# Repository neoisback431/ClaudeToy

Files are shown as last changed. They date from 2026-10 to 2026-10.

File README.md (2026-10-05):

# ClaudeToy

Un petit compagnon physique pour Claude Desktop : un écran rond avec **Clawd**, la mascotte pixel-art de
Claude Code, qui réagit à ce que fait Claude (au travail, en attente de validation, terminé…) et te laisse
**approuver ou refuser** les demandes de permission depuis un bouton tactile.

*A tiny physical Claude Desktop companion on an ESP32-S3 + round GC9A01 display, with touch buttons to approve or deny
permission prompts. Port of the official [claude-desktop-buddy](https://github.com/anthropics/claude-desktop-buddy)
(M5StickC Plus) to other hardware, with a 3D-printable case.*

<table>
  <tr>
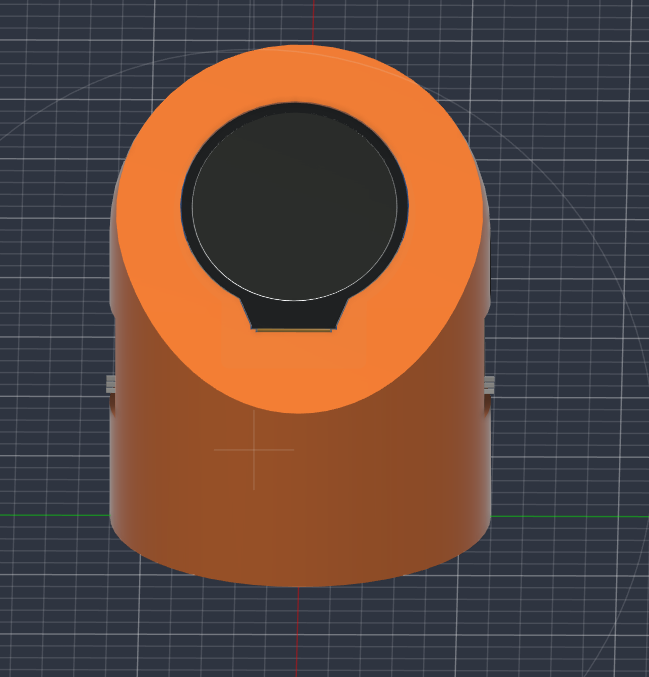
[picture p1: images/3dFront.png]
Vue de face du boîtier
    <td align="center"><br><sub>Face avant : l'écran rond sur la face inclinée</sub></td>
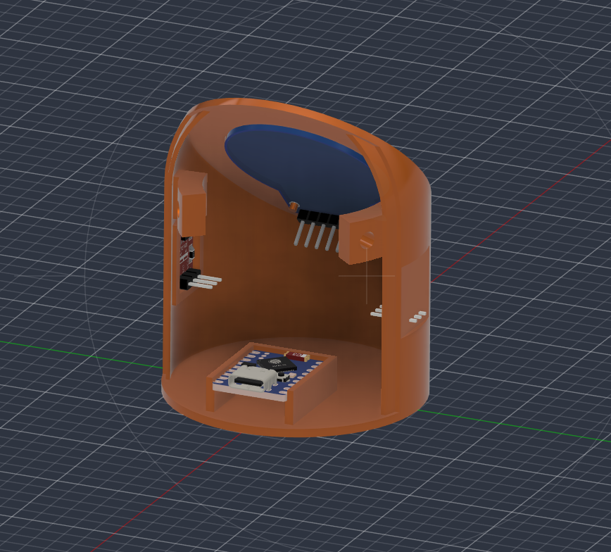
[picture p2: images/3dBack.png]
Vue en coupe du boîtier
    <td align="center"><br><sub>Vue arrière (trappe retirée) : ESP32-S3 et modules dans le corps</sub></td>
  </tr>
</table>

> **Base logicielle :** la partie logicielle de ce projet (firmware, protocole Bluetooth, animaux, menus, statistiques) repose en grande
> partie sur le projet [anthropics/claude-desktop-buddy](https://github.com/anthropics/claude-desktop-buddy) (licence MIT, © Anthropic, PBC),
> adapté ici à d'autres composants. Voir [Licence et crédits](#licence-et-crédits).
>
> Projet communautaire non officiel, sans lien avec Anthropic. La fonction « Hardware Buddy » de Claude Desktop est
> réservée au mode développeur et n'est pas une fonctionnalité officiellement supportée.

## Ce que ça fait

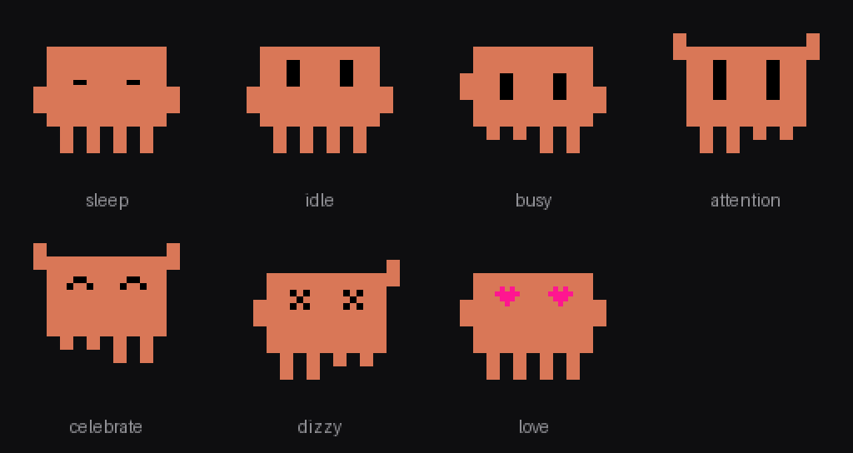
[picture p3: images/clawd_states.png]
Les 7 états de Clawd
<p align="center"><br><sub>Les sept états de Clawd (rendu illustratif de l'animation du firmware)</sub></p>

- **Clawd réagit à Claude** : il dort, attend, travaille, s'inquiète quand une permission est demandée, fête une réussite…
- **Approbation physique** : tap pour approuver, un autre geste (ou un 2e bouton) pour refuser.
- **Écran de veille** : heure et date, tokens du jour, niveau et progression, sessions en cours/en attente,
  état du Bluetooth, dernier message de Claude.
- **Bluetooth LE chiffré** avec appairage par code à 6 chiffres affiché à l'écran.

## Informations affichées

Tout vient de Claude Desktop, par Bluetooth LE : l'état des sessions, les tokens, les dernières lignes du transcript,
la demande de permission en cours (outil + commande), l'heure et ton prénom. Rien ne transite par Internet.

| Écran | Quand | Contenu |
| ----- | ----- | --- |
| **Veille** | aucune session en cours ni en attente | Heure (deux-points clignotants) et date ; **tokens du jour** ; **niveau** (Lv) avec barre de progression vers le suivant (50 000 tokens par niveau) ; sessions **en cours** et **en attente** ; état du **Bluetooth** (vert = chiffré, orange = non chiffré, gris = déconnecté) ; **dernier message** de Claude sur 2 lignes ; avec la status line : **modèle, effort et % de contexte** (ex. `Opus 4.5 high 42%`) |
| **Bague de contexte** | dès que la status line de Claude Code est branchée (voir plus bas) | 60 points autour du bord de l'écran, remplis dans le sens horaire selon le **contexte utilisé** : vert, puis jaune (60 %), orange (80 %) et rouge (90 %). Disparaît si plus rien n'arrive pendant 30 minutes |
| **Activité** | au moins une session en cours | Clawd en grand et les 3 dernières lignes du transcript (défilement avec le bouton B) |
| **Demande de permission** | Claude attend une validation | Délai d'attente (rouge après 10 s), **nom de l'outil** (ex. `Bash`), **commande ou fichier concerné** sur 2 lignes, rappel des gestes pour approuver ou refuser |
| **Pet** (tap pour y accéder) | à la demande | Page 1 : humeur (4 cœurs), faim (10 pastilles), énergie, niveau, nombre d'approbations et de refus, tokens totaux et du jour. Page 2 : explications |
| **Info** (tap) | à la demande | 6 pages : à propos, boutons, **Claude** (sessions, état du lien, ancienneté du dernier message), **appareil** (durée de fonctionnement, mémoire libre, luminosité), **Bluetooth** (nom `Claude-XXXX`, adresse, marche à suivre), crédits |
| **Menu** (appui long ou double tap) | à la demande | Réglages (luminosité, son, LED, ordre des écrans, changement d'animal, réinitialisation), éteindre, aide, mode démo |
| **Appairage** | première connexion | Code à 6 chiffres à saisir sur l'ordinateur |
| **Démarrage** | allumage | « Hello! » ou « *Prénom*'s Clawd » |

### Les états de Clawd

| État | Déclencheur |
| ---- | --- |
| sleep | nuit (1 h – 7 h), week-end, ou les 12 s après le réveil de l'écran |
| idle | connecté, rien d'urgent |
| busy | au moins une session en cours (le projet d'origine attendait 3 sessions) |
| attention | une permission attend ta réponse |
| celebrate | tâche terminée, ou niveau gagné |
| heart | permission approuvée en moins de 5 s |
| dizzy | secousse (nécessite un IMU, absent de ce montage) |

Sans IMU et sans batterie, certaines valeurs restent figées : la sieste et l'énergie ne varient pas, et l'écran
« appareil » affiche 0 % de batterie.

## Status line Claude Code (modèle, effort, contexte)

Claude Desktop n'envoie par Bluetooth ni le modèle, ni le niveau d'effort, ni le contexte. Un **mod Claude Code**,
[`mod/claudetoy-statusline`](mod/claudetoy-statusline), les lit et les envoie à la carte par le **port USB** : modèle, effort,
% de contexte et quotas 5 h / 7 j (uniquement ces champs : ni dossier de travail, ni dépôt Git). Il fonctionne dans
Claude Desktop (onglet Code) comme dans la CLI, et n'affiche rien dans Claude.

```bash
pip install pyserial
claude plugin marketplace add neoisback431/ClaudeToy
claude plugin install claudetoy-statusline@claudetoy
```

Puis `claude plugin list` doit indiquer le plugin comme chargé ; relance Claude Desktop. Si tu avais un bloc `statusLine`
pointant vers le script, retire-le de `~/.claude/settings.json` pour éviter un double envoi. Options du plugin (`/config`) :
`python` (exécutable, `python` par défaut) et `refreshSeconds` (5 par défaut).

- **Testé avec Claude Desktop** : modèle, contexte, quotas et effort remontent sur la bague. Le mod a besoin d'une version de
  Claude Code qui gère les mods ; sinon `claude plugin list` affiche une erreur de chargement.
- **Sans le mod** (CLI seule) : le script [`claudetoy_statusline.py`](mod/claudetoy-statusline/claudetoy_statusline.py) peut aussi
  servir de status line, dans `~/.claude/settings.json` :
  `"statusLine": {"type": "command", "command": "python C:/chemin/vers/mod/claudetoy-statusline/claudetoy_statusline.py", "refreshInterval": 5}`
  (barres obliques `/` sous Windows).
- L'effort est lu à chaque requête au modèle : il reste vide jusqu'à la première réponse d'une session.
- La carte doit être branchée en USB au PC qui exécute Claude Code. Si le port est occupé (flash, moniteur série) ou la carte absente,
  l'envoi est simplement ignoré.
- Les quotas 5 h / 7 j ne sont fournis que pour les abonnements Pro et Max, et le contexte reste inconnu pendant la première minute
  d'une session.
- Avec plusieurs sessions, la dernière valeur reçue s'affiche.
- L'effort est abrégé (`medium` devient `med`) et le nom du modèle est raccourci pour tenir à l'écran.
- Le script garde ses 100 derniers passages dans `%TEMP%\claudetoy_statusline.log` (heure, session, valeurs envoyées) pour diagnostiquer.
- Format du message (une ligne JSON) : `{"cc":{"m":"Opus 4.5","e":"high","c":42,"h":23,"d":41}}` (`-1` = inconnu).

## Nomenclature (BOM)

| Qté | Composant | Remarque |
| --- | --- | --- |
| 1 | ESP32-S3 Super Mini | USB natif et BLE 5. Ne convient pas : ESP32-C3 (pas de tactile natif, moins à l'aise) ni ESP8266 (pas de BLE) |
| 1 | Écran rond GC9A01 1,28" SPI, 240×240 | Versions à 7 ou 8 broches ; la broche BLK (rétroéclairage) est facultative |
| 1 à 2 | Module tactile capacitif TTP223 | 1 en mode 1 bouton, 2 en mode 2 boutons |
| 1 | Câble USB-C (données) | Alimentation et flash |
| — | Fils souples ou Dupont, barrettes à souder | 7 à 8 fils pour l'écran, 3 par module tactile |
| — | Fixations (vis, colle) | Selon ton montage |
| 1 | Corps principal imprimé en 3D | [`3dParts/Corps principal.stl`](3dParts/Corps%20principal.stl) |
| 1 | Trappe imprimée en 3D | [`3dParts/Trappe.stl`](3dParts/Trappe.stl) |

Optionnel, **non géré par le firmware** : accu Li-ion rechargeable et chargeur, schéma dans [BATTERY.md](BATTERY.md).

## Câblage

<p align="center">Schéma de câblage</p>

| Écran GC9A01 | ESP32-S3 | | Module tactile | ESP32-S3 |
| --- | --- | - | --- | --- |
| VCC | 3V3 | | A : OUT | GPIO 4 |
| GND | GND | | B : OUT (optionnel) | GPIO 2 |
| SCL | GPIO 5 | | VCC (A et B) | 3V3 |
| SDA | GPIO 6 | | GND (A et B) | GND |
| CS | GPIO 7 | | | |
| DC | GPIO 8 | | | |
| RST | GPIO 9 | | | |
| BLK (si présent) | GPIO 10 | | | |

Détails et conseils : [WIRING.md](WIRING.md).

## Boîtier 3D

| Fichier | Contenu |
| --- | --- |
| [`3dParts/Corps principal.stl`](3dParts/Corps%20principal.stl) | Corps cylindrique, environ 60 × 60 × 74 mm, face supérieure inclinée pour l'écran |
| [`3dParts/Trappe.stl`](3dParts/Trappe.stl) | Trappe d'accès, environ 22 × 58 × 71 mm |
| [`3dParts/claude_toy.f3z`](3dParts/claude_toy.f3z) | Projet complet Fusion (archive) |
| [`3dParts/claud_toy.f3d`](3dParts/claud_toy.f3d) | Modèle Fusion |

Les dimensions ci-dessus sont lues dans les fichiers STL. Les fichiers Fusion permettent d'adapter le boîtier
(emplacement des modules, taille de la carte).

## Compiler et flasher

```bash
pip install platformio esptool
python -m platformio run -t upload
```

L'upload passe par l'esptool récent (PlatformIO embarque une version qui rate le reset automatique sur l'USB natif
de l'S3). Si la carte n'est pas détectée : maintenir **BOOT**, rebrancher l'USB, relâcher après 2 s.

## Appairage avec Claude Desktop

**Documentation officielle :** [section « Pairing » du dépôt claude-desktop-buddy](https://github.com/anthropics/claude-desktop-buddy#pairing)
et [protocole détaillé (REFERENCE.md)](https://github.com/anthropics/claude-desktop-buddy/blob/main/REFERENCE.md#enabling-the-bridge).

En résumé :

1. Dans Claude Desktop (macOS ou Windows) : `Help → Troubleshooting → Enable Developer Mode`.
2. `Developer → Open Hardware Buddy…` puis **Connect** et choisir `Claude-XXXX`.
3. Saisir le code à 6 chiffres affiché sur l'écran.

Ensuite, la reconnexion est automatique. Le pont Bluetooth n'est disponible qu'en mode développeur : ce n'est pas une
fonctionnalité officiellement supportée.

## Boutons

Mode 2 boutons (par défaut, `-DBUDDY_BTNB_PIN=2`) :

| Bouton | Action |
| --- | --- |
| A, tap | approuver / écran suivant |
| A, appui long | menu |
| B | refuser / valider / page suivante |

Mode 1 bouton (commenter `BUDDY_BTNB_PIN`) : tap = A, appui long = B, double tap = menu.

## Ce qui change par rapport à l'original

- Couche de compatibilité `src/M5StickCPlus.h` + `src/m5shim.cpp` : l'API M5Stack est émulée (écran TFT_eSPI, rétroéclairage PWM,
  boutons tactiles, horloge logicielle), le reste du firmware est quasi inchangé.
- Nouvelle espèce `clawd` ([src/buddies/clawd.cpp](src/buddies/clawd.cpp)), dessinée en pixels, avec les 7 états animés.
- Tableau de bord de veille (heure, tokens du jour, niveau, sessions, Bluetooth, dernier message).
- Interface réduite à 135×208 px, centrée dans le cercle.
- Bague de contexte et ligne modèle/effort alimentées par la status line de Claude Code, via USB.

## État

- Testé sur le matériel : compilation, flash, affichage, mode 1 bouton, appairage Bluetooth avec Claude Desktop.
- Mode 2 boutons : implémenté, pas encore validé sur le matériel.
- Pas d'IMU : pas de secousse, de sieste face cachée ni d'horloge paysage. Pas de gestion de batterie dans le firmware.
- Les personnages GIF ne sont pas fournis (les GIF « bufo » du dépôt d'origine sont des œuvres de tiers) ; voir
  `tools/prep_character.py` et `tools/flash_character.py`.

## Licence et crédits

**Ce projet est un dérivé de [anthropics/claude-desktop-buddy](https://github.com/anthropics/claude-desktop-buddy)**
(licence MIT, © 2026 Anthropic, PBC). La partie logicielle s'appuie en grande partie sur ce dépôt, repris et adapté :

| Repris du projet d'origine (avec adaptations légères) | Ajouté ou réécrit ici |
| --- | --- |
| Protocole Bluetooth LE et appairage chiffré (`ble_bridge`) | Couche de compatibilité M5StickC Plus → ESP32-S3 (`M5StickCPlus.h`, `m5shim.cpp`) |
| Réception des données de Claude Desktop, statistiques, niveaux (`data.h`, `stats.h`, `xfer.h`) | Espèce `clawd` en pixel-art et ses animations |
| Moteur d'animation, 18 animaux ASCII, personnages GIF (`buddy`, `character`, `buddies/`) | Tableau de bord de veille |
| Menus, réglages, écrans Pet et Info, scripts `tools/` | Gestes sur boutons tactiles, mode 1 ou 2 boutons |
| | Câblage, documentation, boîtier 3D |

La licence MIT d'origine est conservée telle quelle dans [LICENSE](LICENSE), comme elle l'exige. Merci aux auteurs du
projet d'origine, dont le dépôt contient aussi la documentation complète du protocole.

Clawd est la mascotte de Claude Code ; le dessin pixel-art de ce dépôt est une réinterprétation non officielle.

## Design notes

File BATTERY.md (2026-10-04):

# Alimentation sur batterie — Li-ion 16340 + chargeur TP4057

## ⚠️ À vérifier avant de brancher quoi que ce soit

- **L'accu doit être un Li-ion RECHARGEABLE 3,7 V (4,2 V pleine charge).** Les piles marquées « LS… » chez
  Saft (ex. LS 17330) sont des lithium-thionyle **non rechargeables** (3,6 V) : les mettre sur un chargeur
  est dangereux (échauffement, fuite, incendie). Cherche « Li-ion », « rechargeable » ou « 4,2 V » sur l'étiquette.
- **Protection obligatoire** : le TP4057 charge, mais ne coupe pas la décharge ni les courts-circuits. Prends un
  accu **protégé** (petit circuit intégré en bout) ou ajoute un module de protection 1S (DW01A + FS8205A).
- **Courant de charge ≤ 0,5 C** : pour ~700 mAh, vise 300 à 350 mA. La plupart des modules TP405x se règlent
  avec la résistance PROG (I ≈ 1200 V / R : 3,3 kΩ ≈ 360 mA). Vérifie la valeur sur ton module (1,2 kΩ = 1 A, trop fort).

## Principe (chemin d'alimentation)

- **Sur USB** (câble branché sur le module chargeur) : l'ESP32 est alimenté par l'USB via D1 ; le MOSFET Q1
  isole l'accu du système, qui se recharge **seul** (la charge se termine correctement).
- **Sur batterie** (USB débranché) : Q1 conduit, l'accu alimente la broche 5V de la carte (chute quasi nulle,
  contrairement à une diode).
- La carte régule ensuite en 3,3 V avec son propre régulateur : l'accu 4,2 → 3,5 V donne un 3V3 stable ; en dessous
  la tension descend doucement. Le firmware coupera vers 3,3 V pour protéger l'accu.

## Schéma

```
                     ┌──────────────────────────┐
   USB-C ───────────►│ IN+        TP4057        │
                     │ (module     chargeur     │
                     │  complet)  BAT+  BAT-    │
                     └──┬───────────┬─────┬─────┘
                        │           │     │
              VUSB ─────┤           │     └──────────────────────────────── GND commun
                        │      ┌────┴─────┐
                        │      │ PROTECTION│  (inutile si accu protégé)
                        │      │ DW01+8205 │
                        │      └────┬─────┘
                        │           │ P+  / P− (vers GND commun)
                        │      ┌────┴─────┐
                        │      │  ACCU    │  Li-ion 16340, 3,7 V
                        │      │  (+) (−) │
                        │      └──────────┘
                        │           │
                        │         [SW] interrupteur à glissière sur le +
                        │           │
                        │         BATSW ──────────┬──── R3 100k ──┬── R4 100k ── GND
                        │           │             │               └─► GPIO 1  (ADC : tension accu ÷2)
                        │           │             │                   + C1 100 nF vers GND
                        │       D = Drain         │
                        │      ┌────┴────┐        │
                        │      │   Q1    │ P-MOSFET AO3401A (ou SI2301, IRLML6401)
                        ├──────┤ G       │
                        │      └────┬────┘
                        │       S = Source
                        │           │
                        │    ┌──────┴──────────────── SYS ───┬──► carte S3 : broche 5V
                        │    │                               │
                        └─►|─┘  D1 Schottky SS14 / 1N5819    ├─ C2 100 µF (près de la carte) vers GND
                      (anode = VUSB, cathode = SYS)          │
                                                             └─► (écran GC9A01 : VCC reste sur 3V3 de la carte)

   Grille de Q1 : reliée à VUSB, plus R1 100 kΩ de la grille vers GND (tire la grille à 0 V sans USB → Q1 passant).

   Détection USB :  VUSB ── R5 100k ──┬── R6 100k ── GND
                                       └─► GPIO 3   + C3 100 nF vers GND
```

Résumé des connexions :

| De | Vers |
|----|---|
| Chargeur IN+ (5 V USB) | D1 anode, grille de Q1, R1, R5 |
| D1 cathode | SYS |
| Chargeur BAT+ | accu + (via la protection) |
| Accu + | interrupteur SW → BATSW |
| BATSW | Q1 drain, R3 |
| Q1 source | SYS |
| SYS | broche **5V** de la carte S3, C2 |
| R1 (autre bout) | GND |
| R3 / R4 (point milieu) | **GPIO 1**, C1 vers GND |
| R5 / R6 (point milieu) | **GPIO 3**, C3 vers GND |
| GND chargeur, accu −, GND carte, GND écran | tous reliés ensemble |

Le buzzer optionnel (GPIO 1) n'est plus disponible : la broche sert à mesurer l'accu.

## Pièces

- Accu Li-ion rechargeable 16340 (idéalement protégé) + support
- Module chargeur TP4057 avec prise USB (courant réglé à ~350 mA)
- (Option) module de protection 1S DW01A + FS8205A si l'accu n'est pas protégé
- Q1 : MOSFET canal P, SOT-23, ex. AO3401A, SI2301 ou IRLML6401
- D1 : diode Schottky SS14 ou 1N5819
- R1, R3, R4, R5, R6 : 5 × 100 kΩ
- C1, C3 : 2 × 100 nF ; C2 : 100 µF
- Interrupteur à glissière

## Règles d'usage

1. **Interrupteur sur OFF avant de brancher l'USB-C de la carte S3** (flash, console). Sinon le 5 V de la carte
   peut repousser du courant dans Q1 et l'accu. Pour recharger, utilise l'USB du **module chargeur**.
2. Ne jamais court-circuiter l'accu ; ne jamais le charger sans la protection.
3. Autonomie estimée : ~6 à 8 h avec Bluetooth et rétroéclairage au maximum ; l'écran s'éteint seul après 30 s
   sans interaction sur batterie (c'est déjà dans le firmware d'origine).

## L'« indicateur de charge » que tu as

Un indicateur à LED branché directement sur l'accu (BAT+/BAT−) fonctionne tel quel, sans lien avec l'ESP32.
Le firmware, lui, affichera le pourcentage mesuré sur GPIO 1.

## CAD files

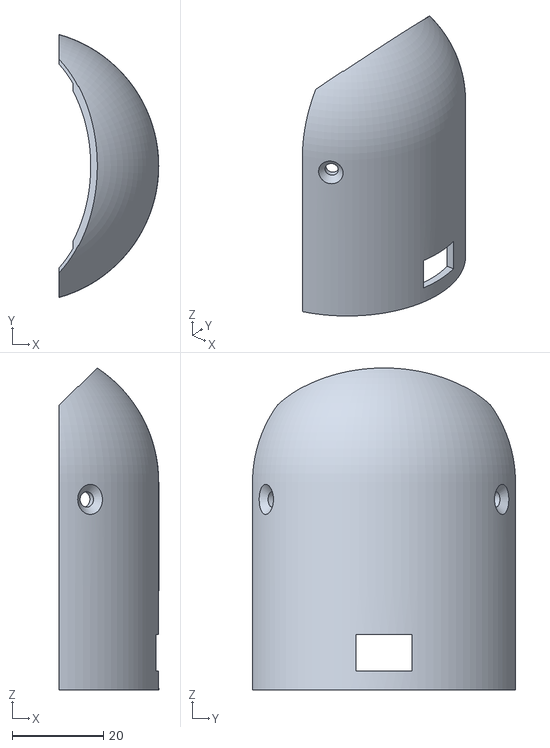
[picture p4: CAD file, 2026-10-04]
3dParts/Trappe.stl
21.9 x 57.7 x 70.7

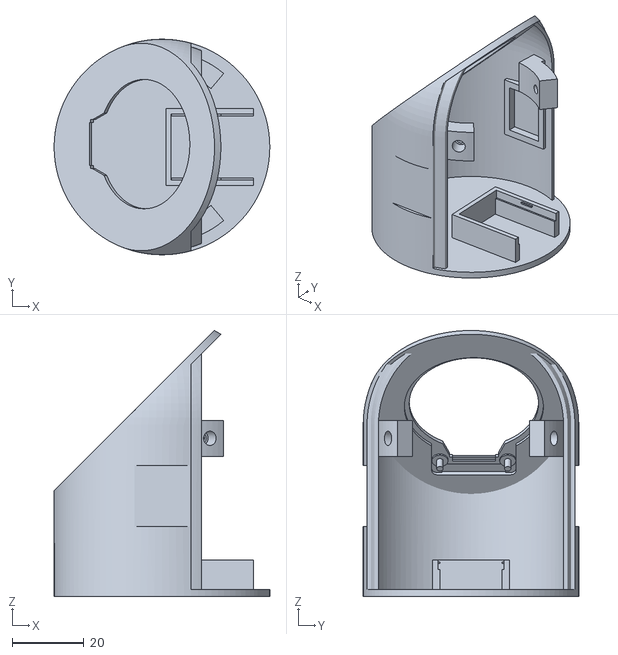
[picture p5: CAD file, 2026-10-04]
3dParts/Corps principal.stl
60.0 x 60.0 x 74.0

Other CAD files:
3dParts/claud_toy.f3d
3dParts/claude_toy.f3z

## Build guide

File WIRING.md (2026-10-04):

# Câblage — ESP32-S3 Super Mini + GC9A01 1.28" + boutons tactiles

Schéma de câblage

| Écran GC9A01 | ESP32-S3 Super Mini | Note |
| --- | --- | ---- |
| VCC | 3V3 | pas 5V |
| GND | GND | |
| SCL (CLK) | GPIO 5 | SPI SCK |
| SDA (MOSI) | GPIO 6 | SPI MOSI |
| DC | GPIO 8 | |
| CS | GPIO 7 | |
| RST | GPIO 9 | |
| BLK | GPIO 10 | rétroéclairage, PWM (variateur) ; **facultatif** : certains modules n'ont pas cette broche (rétroéclairage toujours allumé) |

| Périphérique | Broche | Note |
| --- | --- | ---- |
| Bouton A (module tactile TTP223) | GPIO 4 | VCC→3V3, GND→GND, OUT→GPIO 4 |
| Bouton B (module tactile TTP223) | GPIO 2 | VCC→3V3, GND→GND, OUT→GPIO 2 |
| Buzzer passif (optionnel)| GPIO 1 | + décommenter `-DBUDDY_BUZZER_PIN=1` dans `platformio.ini` |

Seules les broches GPIO 1 à 10 sont utilisées. Évitées : 0, 3, 45, 46 (strapping), 19 et 20 (USB natif).
Carte requise : **ESP32-S3** (le C3 n'a pas de capteur tactile). Vérifie sur la sérigraphie que
les GPIO 1 à 10 sont bien sorties sur ta carte.

## Boutons

| Bouton | Action |
| --- | --- |
| A (tap) | approuver la demande / écran suivant / option suivante dans les menus |
| A (appui long 0,6 s) | ouvrir/fermer le menu |
| B | refuser la demande / valider dans les menus / page suivante |

Mode 1 seul bouton (si B absent) : retirer `-DBUDDY_BTNB_PIN=2` de `platformio.ini` ; tap = A,
double tap = B, appui long = menu.

## Flash

```bash
python -m platformio run -t upload
```

L'upload utilise l'esptool récent (`pip install -U esptool`), qui gère le reset automatique sur l'USB natif
de l'S3 : pas besoin de BOOT. En cas de souci, maintenir BOOT, rebrancher l'USB, relâcher.
Le moniteur série est en USB natif (`python -m platformio device monitor`).

## Réglages si besoin

Dans `platformio.ini` :
- `-DBUDDY_LCD_INVERT=1` si les couleurs sont inversées.
- `-DBUDDY_TOUCH_DEBUG=1` pour afficher `raw/base/thr` du capteur tactile sur le port série
  (ajuster `BUDDY_TOUCH_PCT` / `BUDDY_TOUCH_MIN_DELTA` si le pad est trop/pas assez sensible).

## Limites connues de ce premier port

- Pas testé sur le matériel : le build passe, le rendu et la sensibilité tactile restent à valider.
- L'UI d'origine est un portrait 135×240 centré sur l'écran rond : le haut et le bas (~20 px) sont
  rognés par le cercle (ligne « tap: approve / 2x: deny » en bas, notamment).
- Pas d'IMU : pas de « dizzy » (secousse), pas de sieste face cachée, horloge en portrait uniquement.
- Pas de batterie : les écrans d'info affichent 0 %. L'écran ne s'éteint jamais seul (alimentation USB).

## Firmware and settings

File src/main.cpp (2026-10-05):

#include <M5StickCPlus.h>
#include <LittleFS.h>
#include <stdarg.h>
#include "ble_bridge.h"
#include "data.h"
#include "buddy.h"

// UI wording depends on the input hardware (two touch buttons vs one with gestures).
#ifdef BUDDY_BTNB_PIN
  #define HINT_APPROVE "A: approve"
  #define HINT_DENY    "B: deny"
  #define HINT_DENY_DX 54
#else
  #define HINT_APPROVE "tap: approve"
  #define HINT_DENY    "hold: deny"
  #define HINT_DENY_DX 66
#endif

TFT_eSprite spr = TFT_eSprite(&M5.Lcd);

// Advertise as "Claude-XXXX" (last two BT MAC bytes) so multiple sticks
// in one room are distinguishable in the desktop picker. Name persists in
// btName for the BLUETOOTH info page.
static char btName[16] = "Claude";
static void startBt() {
  uint8_t mac[6] = {0};
  esp_read_mac(mac, ESP_MAC_BT);
  snprintf(btName, sizeof(btName), "Claude-%02X%02X", mac[4], mac[5]);
  bleInit(btName);
}

#include "character.h"
#include "stats.h"
const int W = 135, H = 208;   // shortened from 240 so the bottom HUD stays inside the round panel
const int CX = W / 2;
const int CY_BASE = 120;
// Round 240x240 panel: the 135x240 portrait UI is centred; corners are clipped by the circle.
const int SPR_X = (240 - W) / 2, SPR_Y = 12;
#ifdef BUDDY_LED_PIN
const int LED_PIN = BUDDY_LED_PIN;   // optional external LED, active-low (3V3 -> R -> LED -> pin)
#else
const int LED_PIN = -1;
#endif
static inline void ledSet(bool on) { if (LED_PIN >= 0) digitalWrite(LED_PIN, on ? LOW : HIGH); }

// Colors used across multiple UI surfaces
const uint16_t HOT   = 0xFA20;   // red-orange: warnings, impatience, deny
const uint16_t PANEL = 0x2104;   // overlay panel background

enum PersonaState { P_SLEEP, P_IDLE, P_BUSY, P_ATTENTION, P_CELEBRATE, P_DIZZY, P_HEART };
const char* stateNames[] = { "sleep", "idle", "busy", "attention", "celebrate", "dizzy", "heart" };

TamaState    tama;
PersonaState baseState   = P_SLEEP;
PersonaState activeState = P_SLEEP;
uint32_t     oneShotUntil = 0;
uint32_t     lastShakeCheck = 0;
float        accelBaseline = 1.0f;
unsigned long t = 0;

// Menu
bool    menuOpen    = false;
uint8_t menuSel     = 0;
uint8_t brightLevel = 4;           // 0..4 → ScreenBreath 20..100
bool    btnALong    = false;

enum DisplayMode { DISP_NORMAL, DISP_PET, DISP_INFO, DISP_COUNT };
uint8_t displayMode = DISP_NORMAL;
uint8_t infoPage = 0;
uint8_t petPage = 0;
const uint8_t PET_PAGES = 2;
uint8_t msgScroll = 0;
uint16_t lastLineGen = 0;
char     lastPromptId[40] = "";
uint32_t lastInteractMs = 0;
bool     dimmed = false;
bool     screenOff = false;
bool     swallowBtnA = false;
bool     swallowBtnB = false;
bool     buddyMode = false;
bool     gifAvailable = false;
const uint8_t SPECIES_GIF = 0xFF;   // species NVS sentinel: use the installed GIF

// Cycle GIF (if installed) → ASCII species 0..N-1 → GIF. Persisted to the
// existing "species" NVS key; 0xFF means GIF mode.
static void nextPet() {
  uint8_t n = buddySpeciesCount();
  if (!buddyMode) {                          // GIF → species 0
    buddyMode = true;
    buddySetSpeciesIdx(0);
    speciesIdxSave(0);
  } else if (buddySpeciesIdx() + 1 >= n && gifAvailable) {  // last species → GIF
    buddyMode = false;
    speciesIdxSave(SPECIES_GIF);
  } else {                                   // species i → species i+1
    buddyNextSpecies();
  }
  characterInvalidate();
  if (buddyMode) buddyInvalidate();
}
uint32_t wakeTransitionUntil = 0;
const uint32_t SCREEN_OFF_MS = 30000;

bool     napping = false;
uint32_t napStartMs = 0;
uint32_t promptArrivedMs = 0;

// Face-down = Z-axis dominant and negative. Debounced so a toss doesn't count.
static bool isFaceDown() {
  float ax, ay, az;
  M5.Imu.getAccelData(&ax, &ay, &az);
  return az < -0.7f && fabsf(ax) < 0.4f && fabsf(ay) < 0.4f;
}

static void applyBrightness() { M5.Axp.ScreenBreath(20 + brightLevel * 20); }

static void wake() {
  lastInteractMs = millis();
  if (screenOff) {
    M5.Axp.SetLDO2(true);
    applyBrightness();
    screenOff = false;
    wakeTransitionUntil = millis() + 12000;
  }
  if (dimmed) { applyBrightness(); dimmed = false; }
}
bool     responseSent = false;

static void beep(uint16_t freq, uint16_t dur) {
  if (settings().sound) M5.Beep.tone(freq, dur);
}

static void sendCmd(const char* json) {
  Serial.println(json);
  size_t n = strlen(json);
  bleWrite((const uint8_t*)json, n);
  bleWrite((const uint8_t*)"\n", 1);
}
const uint8_t INFO_PAGES = 6;
const uint8_t INFO_PG_BUTTONS = 1;
const uint8_t INFO_PG_CREDITS = 5;

void applyDisplayMode() {
  bool peek = displayMode != DISP_NORMAL;
  characterSetPeek(peek);
  buddySetPeek(peek);
  // Clear the whole sprite on mode switch. drawInfo/drawPet clear their
  // own regions when they run, but when you switch FROM info/pet TO normal,
  // those functions stop running and their stale pixels stay behind. Full
  // clear is cheap and guarantees no leftovers between modes.
  spr.fillSprite(0x0000);
  characterInvalidate();  // redraws character on next tick (text mode path)
}

const char* menuItems[] = { "settings", "turn off", "help", "about", "demo", "close" };
const uint8_t MENU_N = 6;

bool    settingsOpen = false;
uint8_t settingsSel  = 0;
const char* settingsItems[] = { "brightness", "sound", "bluetooth", "wifi", "led", "transcript", "clock rot", "ascii pet", "reset", "back" };
const uint8_t SETTINGS_N = 10;

bool    resetOpen = false;
uint8_t resetSel  = 0;
const char* resetItems[] = { "delete char", "factory reset", "back" };
const uint8_t RESET_N = 3;
static uint32_t resetConfirmUntil = 0;
static uint8_t  resetConfirmIdx = 0xFF;

static void applySetting(uint8_t idx) {
  Settings& s = settings();
  switch (idx) {
    case 0:
      brightLevel = (brightLevel + 1) % 5;
      applyBrightness();
      return;
    case 1: s.sound = !s.sound; break;
    case 2:
      // BT toggle is a stored preference only — BLE stays live. Turning
      // BLE off cleanly would require tearing down the BLE stack which
      // the Arduino BLE library doesn't do reliably. If we need a
      // hard-off someday, stop advertising via BLEDevice::getAdvertising().
      s.bt = !s.bt;
      break;
    case 3: s.wifi = !s.wifi; break;   // stored only — no WiFi stack linked
    case 4: s.led = !s.led; break;
    case 5: s.hud = !s.hud; break;
    case 6: s.clockRot = (s.clockRot + 1) % 3; break;
    case 7: nextPet(); return;
    case 8: resetOpen = true; resetSel = 0; resetConfirmIdx = 0xFF; return;
    case 9: settingsOpen = false; characterInvalidate(); return;
  }
  settingsSave();
}

// Tap-twice confirm: first tap arms (label flips to "really?"), second
// within 3s executes. Scrolling away clears the arm.
static void applyReset(uint8_t idx) {
  uint32_t now = millis();
  bool armed = (resetConfirmIdx == idx) && (int32_t)(now - resetConfirmUntil) < 0;

  if (idx == 2) { resetOpen = false; return; }

  if (!armed) {
    resetConfirmIdx = idx;
    resetConfirmUntil = now + 3000;
    beep(1400, 60);
    return;
  }

  beep(800, 200);
  if (idx == 0) {
    // delete char: wipe /characters/, reboot into ASCII mode
    File d = LittleFS.open("/characters");
    if (d && d.isDirectory()) {
      File e;
      while ((e = d.openNextFile())) {
        char path[80];
        snprintf(path, sizeof(path), "/characters/%s", e.name());
        if (e.isDirectory()) {
          File f;
          while ((f = e.openNextFile())) {
            char fp[128];
            snprintf(fp, sizeof(fp), "%s/%s", path, f.name());
            f.close();
            LittleFS.remove(fp);
          }
          e.close();
          LittleFS.rmdir(path);
        } else {
          e.close();
          LittleFS.remove(path);
        }
      }
      d.close();
    }
  } else {
    // factory reset: NVS namespace wipe + filesystem format + BLE bonds.
    // Clears stats, owner, petname, species, settings, GIF characters,
    // and any stored LTKs so the next desktop has to re-pair.
    _prefs.begin("buddy", false);
    _prefs.clear();
    _prefs.end();
    LittleFS.format();
    bleClearBonds();
  }
  delay(300);
  ESP.restart();
}

// Footer hint row inside a menu panel: "<downLbl> ↓  <rightLbl> →" with
// pixel triangles. Panels add MENU_HINT_H to height and call this at bottom.
const int MENU_HINT_H = 14;
static void drawMenuHints(const Palette& p, int mx, int mw, int hy,
                          const char* downLbl = "A", const char* rightLbl = "B") {
  spr.drawFastHLine(mx + 6, hy - 4, mw - 12, p.textDim);
  spr.setTextColor(p.textDim, PANEL);
  // 6px/glyph at size 1; triangle goes 4px after the label ends
  int x = mx + 8;
  spr.setCursor(x, hy); spr.print(downLbl);
  x += strlen(downLbl) * 6 + 4;
  spr.fillTriangle(x, hy + 1, x + 6, hy + 1, x + 3, hy + 6, p.textDim);
  x = mx + mw / 2 + 4;
  spr.setCursor(x, hy); spr.print(rightLbl);
  x += strlen(rightLbl) * 6 + 4;
  spr.fillTriangle(x, hy, x, hy + 6, x + 5, hy + 3, p.textDim);
}

static void drawSettings() {
  const Palette& p = characterPalette();
  int mw = 118, mh = 16 + SETTINGS_N * 14 + MENU_HINT_H;
  int mx = (W - mw) / 2, my = (H - mh) / 2;
  spr.fillRoundRect(mx, my, mw, mh, 4, PANEL);
  spr.drawRoundRect(mx, my, mw, mh, 4, p.textDim);
  spr.setTextSize(1);
  Settings& s = settings();
  bool vals[] = { s.sound, s.bt, s.wifi, s.led, s.hud };
  for (int i = 0; i < SETTINGS_N; i++) {
    bool sel = (i == settingsSel);
    spr.setTextColor(sel ? p.text : p.textDim, PANEL);
    spr.setCursor(mx + 6, my + 8 + i * 14);
    spr.print(sel ? "> " : "  ");
    spr.print(settingsItems[i]);
    spr.setCursor(mx + mw - 36, my + 8 + i * 14);
    spr.setTextColor(p.textDim, PANEL);
    if (i == 0) {
      spr.printf("%u/4", brightLevel);
    } else if (i >= 1 && i <= 5) {
      spr.setTextColor(vals[i-1] ? GREEN : p.textDim, PANEL);
      spr.print(vals[i-1] ? " on" : "off");
    } else if (i == 6) {
      static const char* const RN[] = { "auto", "port", "land" };
      spr.print(RN[s.clockRot]);
    } else if (i == 7) {
      uint8_t total = buddySpeciesCount() + (gifAvailable ? 1 : 0);
      uint8_t pos   = buddyMode ? buddySpeciesIdx() + 1 : total;
      spr.printf("%u/%u", pos, total);
    }
  }
  drawMenuHints(p, mx, mw, my + mh - 12, "Next", "Change");
}

static void drawReset() {
  const Palette& p = characterPalette();
  int mw = 118, mh = 16 + RESET_N * 14 + MENU_HINT_H;
  int mx = (W - mw) / 2, my = (H - mh) / 2;
  spr.fillRoundRect(mx, my, mw, mh, 4, PANEL);
  spr.drawRoundRect(mx, my, mw, mh, 4, HOT);
  spr.setTextSize(1);
  for (int i = 0; i < RESET_N; i++) {
    bool sel = (i == resetSel);
    spr.setTextColor(sel ? p.text : p.textDim, PANEL);
    spr.setCursor(mx + 6, my + 8 + i * 14);
    spr.print(sel ? "> " : "  ");
    bool armed = (i == resetConfirmIdx) &&
                 (int32_t)(millis() - resetConfirmUntil) < 0;
    if (armed) spr.setTextColor(HOT, PANEL);
    spr.print(armed ? "really?" : resetItems[i]);
  }
  drawMenuHints(p, mx, mw, my + mh - 12);
}

void menuConfirm() {
  switch (menuSel) {
    case 0: settingsOpen = true; menuOpen = false; settingsSel = 0; break;
    case 1: M5.Axp.PowerOff(); break;
    case 2:
    case 3:
      menuOpen = false;
      displayMode = DISP_INFO;
      infoPage = (menuSel == 2) ? INFO_PG_BUTTONS : INFO_PG_CREDITS;
      applyDisplayMode();
      characterInvalidate();
      break;
    case 4: dataSetDemo(!dataDemo()); break;
    case 5: menuOpen = false; characterInvalidate(); break;
  }
}

void drawMenu() {
  const Palette& p = characterPalette();
  int mw = 118, mh = 16 + MENU_N * 14 + MENU_HINT_H;
  int mx = (W - mw) / 2, my = (H - mh) / 2;
  spr.fillRoundRect(mx, my, mw, mh, 4, PANEL);
  spr.drawRoundRect(mx, my, mw, mh, 4, p.textDim);
  spr.setTextSize(1);
  for (int i = 0; i < MENU_N; i++) {
    bool sel = (i == menuSel);
    spr.setTextColor(sel ? p.text : p.textDim, PANEL);
    spr.setCursor(mx + 6, my + 8 + i * 14);
    spr.print(sel ? "> " : "  ");
    spr.print(menuItems[i]);
    if (i == 4) spr.print(dataDemo() ? "  on" : "  off");
  }
  drawMenuHints(p, mx, mw, my + mh - 12);
}

// Clock orientation: gravity along the in-plane X axis means the stick is
// on its side. Signed counter for hysteresis on both transitions — same
// pattern as face-down nap.
//   0 = portrait (sprite path, pet sleeps underneath)
//   1 = landscape, BtnA-side down (M5.Lcd rotation 1)
//   3 = landscape, USB-side down (M5.Lcd rotation 3)
static uint8_t clockOrient   = 0;
static int8_t  orientFrames  = 0;
static uint8_t paintedOrient = 0;
// RTC and IMU share an I2C bus. Reading the RTC at 60fps starves the IMU
// reads in clockUpdateOrient — orientation detection gets noisy. Cache the
// time once per second; mood logic and drawClock both read from here.
static RTC_TimeTypeDef _clkTm;
static RTC_DateTypeDef _clkDt;
uint32_t               _clkLastRead = 0;   // zeroed by data.h on time-sync
static bool            _onUsb       = false;
static void clockRefreshRtc() {
  if (millis() - _clkLastRead < 1000) return;
  _clkLastRead = millis();
  _onUsb = M5.Axp.GetVBusVoltage() > 4.0f;
  M5.Rtc.GetTime(&_clkTm);
  M5.Rtc.GetDate(&_clkDt);
}
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
void loop() {
  M5.update();
  M5.Beep.update();
  t++;
  uint32_t now = millis();
#ifdef BUDDY_DEBUG_LOG
  static uint32_t lastLog = 0;
  if (now - lastLog > 2000) {
    lastLog = now;
    Serial.printf("[dbg] up=%lus heap=%u ble=%d sec=%d A=%d B=%d disp=%u state=%s screenOff=%d | tot=%u run=%u wait=%u conn=%d age=%lus tok=%lu lines=%u prompt=%s cc=%d/%d\n",
                  (unsigned long)(now / 1000), (unsigned)ESP.getFreeHeap(),
                  (int)bleConnected(), (int)bleSecure(),
                  (int)M5.BtnA.isPressed(), (int)M5.BtnB.isPressed(),
                  (unsigned)displayMode, stateNames[activeState], (int)screenOff,
                  tama.sessionsTotal, tama.sessionsRunning, tama.sessionsWaiting, (int)tama.connected,
                  (unsigned long)((now - tama.lastUpdated) / 1000), (unsigned long)tama.tokensToday,
                  tama.nLines, tama.promptId[0] ? tama.promptId : "-", (int)ccFresh(), (int)ccInfo().ctx);
  }
#endif

  dataPoll(&tama);
  if (statsPollLevelUp()) triggerOneShot(P_CELEBRATE, 3000);
  baseState = derive(tama);

  // After waking the screen, hold sleep for 12s so users see the wake-up
  // animation. Urgent states (attention, celebrate, busy) override this.
  if (baseState == P_IDLE && (int32_t)(now - wakeTransitionUntil) < 0) baseState = P_SLEEP;

  if ((int32_t)(now - oneShotUntil) >= 0) activeState = baseState;

  // LED: pulse on attention, otherwise off
  if (activeState == P_ATTENTION && settings().led) {
    ledSet((now / 400) % 2);
  } else {
    ledSet(false);
  }

  // shake → dizzy + force scenario advance
  if (now - lastShakeCheck > 50) {
    lastShakeCheck = now;
    if (!menuOpen && !screenOff && checkShake() && (int32_t)(now - oneShotUntil) >= 0) {
      wake();
      triggerOneShot(P_DIZZY, 2000);
      Serial.println("shake: dizzy");
    }
  }

  // BtnA: step through fake scenarios
  // Prompt arrival: beep, reset response flag
  if (strcmp(tama.promptId, lastPromptId) != 0) {
    strncpy(lastPromptId, tama.promptId, sizeof(lastPromptId)-1);
    lastPromptId[sizeof(lastPromptId)-1] = 0;
    responseSent = false;
    if (tama.promptId[0]) {
      promptArrivedMs = millis();
      wake();
      beep(1200, 80);   // alert chirp
      // Jump to the approval screen no matter what was open — drawApproval
      // only runs from drawHUD which only runs in DISP_NORMAL.
      displayMode = DISP_NORMAL;
      menuOpen = settingsOpen = resetOpen = false;
      applyDisplayMode();
      characterInvalidate();
      if (buddyMode) buddyInvalidate();
    }
  }

  bool inPrompt = tama.promptId[0] && !responseSent;

  // Button-press wake. Track which button woke the screen so its full
  // press cycle (including long-press) is swallowed — you don't want
  // BtnA-to-wake to also cycle displayMode or open the menu.
  if (M5.BtnA.isPressed() || M5.BtnB.isPressed()) {
    if (screenOff) {
      if (M5.BtnA.isPressed()) swallowBtnA = true;
      if (M5.BtnB.isPressed()) swallowBtnB = true;
    }
    wake();
  }

  // AXP power button (left side): short-press toggles screen off.
  // Long-press (6s) still powers off the device via AXP hardware.
  if (M5.Axp.GetBtnPress() == 0x02) {
    if (screenOff) {
      wake();
    } else {
      M5.Axp.SetLDO2(false);
      screenOff = true;
    }
  }

#ifdef BUDDY_BTNB_PIN
  bool menuTrigger = M5.BtnA.pressedFor(600) && !btnALong && !swallowBtnA;
#else
  bool menuTrigger = M5.menuGesture;
#endif
  if (menuTrigger) {
#ifdef BUDDY_BTNB_PIN
    btnALong = true;
#endif
    beep(800, 60);
    if (resetOpen) { resetOpen = false; }
    else if (settingsOpen) { settingsOpen = false; characterInvalidate(); }
    else {
      menuOpen = !menuOpen;
      menuSel = 0;
      if (!menuOpen) characterInvalidate();
    }
    Serial.println(menuOpen ? "menu open" : "menu close");
  }
  if (M5.BtnA.wasReleased()) {
    if (!btnALong && !swallowBtnA) {
      if (inPrompt) {
        char cmd[96];
        snprintf(cmd, sizeof(cmd), "{\"cmd\":\"permission\",\"id\":\"%s\",\"decision\":\"once\"}", tama.promptId);
        sendCmd(cmd);
        responseSent = true;
        uint32_t tookS = (millis() - promptArrivedMs) / 1000;
        statsOnApproval(tookS);
        beep(2400, 60);
        if (tookS < 5) triggerOneShot(P_HEART, 2000);
      } else if (resetOpen) {
        beep(1800, 30);
        resetSel = (resetSel + 1) % RESET_N;
        resetConfirmIdx = 0xFF;
      } else if (settingsOpen) {
        beep(1800, 30);
        settingsSel = (settingsSel + 1) % SETTINGS_N;
      } else if (menuOpen) {
        beep(1800, 30);
        menuSel = (menuSel + 1) % MENU_N;
      } else {
        beep(1800, 30);
        displayMode = (displayMode + 1) % DISP_COUNT;
        applyDisplayMode();
      }
    }
    btnALong = false;
    swallowBtnA = false;
#ifndef BUDDY_BTNB_PIN
    swallowBtnB = false;   // a hold that woke the screen is over once the finger lifts
#endif
  }

  // BtnB: pet → heart
  if (M5.BtnB.wasPressed()) {
    if (swallowBtnB) { swallowBtnB = false; }
    else
    if (inPrompt) {
      char cmd[96];
      snprintf(cmd, sizeof(cmd), "{\"cmd\":\"permission\",\"id\":\"%s\",\"decision\":\"deny\"}", tama.promptId);
      sendCmd(cmd);
      responseSent = true;
      statsOnDenial();
      beep(600, 60);
    } else if (resetOpen) {
      beep(2400, 30);
      applyReset(resetSel);
    } else if (settingsOpen) {
      beep(2400, 30);
      applySetting(settingsSel);
    } else if (menuOpen) {
      beep(2400, 30);
      menuConfirm();
    } else if (displayMode == DISP_INFO) {
      beep(2400, 30);
      infoPage = (infoPage + 1) % INFO_PAGES;
    } else if (displayMode == DISP_PET) {
      beep(2400, 30);
      petPage = (petPage + 1) % PET_PAGES;
      applyDisplayMode();
    } else {
      beep(2400, 30);
      msgScroll = (msgScroll >= 30) ? 0 : msgScroll + 1;
    }
  }

  // blink bookkeeping

  // Charging clock: takes over the home screen when on USB power, no
  // overlays, no prompt, no live Claude data, and the RTC has been set
  // by the bridge. Pet sleeps underneath. Exit restores Y via
  // applyDisplayMode() so the next mode-switch isn't visually offset.
  clockRefreshRtc();   // 1Hz internal throttle; also caches _onUsb
  // Show the clock when nothing is happening — bridge heartbeat alone
  // doesn't count as activity (it's the only way to get the RTC synced).
  bool clocking = displayMode == DISP_NORMAL
               && !menuOpen && !settingsOpen && !resetOpen && !inPrompt
               && tama.sessionsRunning == 0 && tama.sessionsWaiting == 0;
  if (clocking) clockUpdateOrient();
  else { clockOrient = 0; orientFrames = 0; paintedOrient = 0; }
  bool landscapeClock = clocking && clockOrient != 0;

  static bool wasClocking = false;
  static bool wasLandscape = false;
  if (clocking != wasClocking || landscapeClock != wasLandscape) {
    if (clocking && !landscapeClock) {
      characterSetPeek(true);
      buddySetPeek(true);          // dashboard needs the pet at peek size
      spr.fillSprite(0x0000);
    } else {
      applyDisplayMode();
    }
    characterInvalidate();
    if (buddyMode) buddyInvalidate();
    wasClocking = clocking;
    wasLandscape = landscapeClock;
  }
  if (clocking && dataRtcValid()) {
    uint8_t dow = clockDow();
    bool weekend = (dow == 0 || dow == 6);
    bool friday  = (dow == 5);

    uint8_t h = _clkTm.Hours;
    if (h >= 1 && h < 7)             activeState = P_SLEEP;
    else if (weekend)                activeState = (now/8000 % 6 == 0) ? P_HEART : P_SLEEP;
    else if (h < 9)                  activeState = (now/6000 % 4 == 0) ? P_IDLE  : P_SLEEP;
    else if (h == 12)                activeState = (now/5000 % 3 == 0) ? P_HEART : P_IDLE;
    else if (friday && h >= 15)      activeState = (now/4000 % 3 == 0) ? P_CELEBRATE : P_IDLE;
    else if (h >= 22 || h == 0)      activeState = (now/7000 % 3 == 0) ? P_DIZZY : P_SLEEP;
    else                             activeState = (now/10000 % 5 == 0) ? P_SLEEP : P_IDLE;
  }

  static uint32_t lastPasskey = 0;
  uint32_t pk = blePasskey();
  if (pk && !lastPasskey) { wake(); beep(1800, 60); }
  lastPasskey = pk;
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

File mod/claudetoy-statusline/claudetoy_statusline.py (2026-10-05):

#!/usr/bin/env python3
"""Status line Claude Code -> ClaudeToy.

Claude Code lance ce script et lui envoie un JSON sur stdin (modèle, niveau d'effort,
contexte, quotas...). Le script :
  1. affiche une ligne de statut dans Claude Code (stdout), comme une status line classique ;
  2. envoie en plus quelques champs à la carte ClaudeToy, sur son port série USB.

Seuls le modèle, l'effort et des pourcentages sont envoyés (pas de dossier, pas de dépôt Git).
Si la carte est absente ou si le port est occupé (flash, moniteur série), l'envoi est ignoré.

Installation : pip install pyserial, puis dans ~/.claude/settings.json :
  "statusLine": { "type": "command",
                  "command": "python C:/chemin/vers/mod/claudetoy-statusline/claudetoy_statusline.py",
                  "refreshInterval": 5 }
"""
import json
import os
import re
import sys
import tempfile
import time

ESPRESSIF_VID = 0x303A


def pct(value):
    """Pourcentage entier 0..100, ou -1 si inconnu."""
    try:
        return max(0, min(100, int(round(float(value)))))
    except (TypeError, ValueError):
        return -1


EFFORT_SHORT = {"medium": "med"}   # l'écran affiche 5 caractères au plus


def short_model(name):
    """« Claude Opus 4.8 (1M context) » -> « Opus 4.8 » (l'écran affiche 10 caractères)."""
    name = (name or "?").strip()
    if name.lower().startswith("claude "):
        name = name[7:]
    name = re.sub(r"\s*\([^)]*\)", "", name).strip()
    return (name or "?")[:15]


def find_port():
    from serial.tools import list_ports
    for p in list_ports.comports():
        if p.vid == ESPRESSIF_VID:
            return p.device
    return None


LAST = os.path.join(tempfile.gettempdir(), "claudetoy_statusline.last")


LOG = os.path.join(tempfile.gettempdir(), "claudetoy_statusline.log")


def note(text):
    """Dernier passage du script + journal des 100 derniers (pour vérifier quand Claude Code l'exécute)."""
    line = "%s %s\n" % (time.strftime("%Y-%m-%d %H:%M:%S"), text)
    try:
        with open(LAST, "w", encoding="utf-8") as f:
            f.write(line)
        try:
            with open(LOG, "r", encoding="utf-8") as f:
                lines = f.readlines()[-99:]
        except Exception:
            lines = []
        lines.append(line)
        with open(LOG, "w", encoding="utf-8") as f:
            f.writelines(lines)
    except Exception:
        pass


def push(payload, raw_info=""):
    try:
        import serial
        port = find_port()
        if not port:
            note("aucune carte Espressif détectée")
            return
        s = serial.Serial()
        s.port = port
        s.baudrate = 115200
        s.timeout = 0.2
        s.write_timeout = 0.3
        # Lignes de contrôle au repos AVANT l'ouverture : évite de redémarrer l'ESP32-S3.
        s.dtr = False
        s.rts = False
        s.open()
        try:
            s.write((json.dumps(payload, separators=(",", ":")) + "\n").encode("utf-8"))
            s.flush()
            note("envoyé sur %s : %s%s" % (port, json.dumps(payload, separators=(",", ":")), raw_info))
        finally:
            s.close()
    except Exception as exc:
        note("échec : %s: %s" % (type(exc).__name__, exc))  # carte absente, port occupé, pyserial manquant...


def main():
    try:
        data = json.load(sys.stdin)
    except Exception:
        data = {}

    model = short_model((data.get("model") or {}).get("display_name"))
    effort = (data.get("effort") or {}).get("level") or ""
    effort = EFFORT_SHORT.get(effort, effort)[:7]
    ctx = pct((data.get("context_window") or {}).get("used_percentage"))
    limits = data.get("rate_limits") or {}
    h5 = pct((limits.get("five_hour") or {}).get("used_percentage"))
    d7 = pct((limits.get("seven_day") or {}).get("used_percentage"))

    print("[%s] effort:%s ctx:%s%%" % (model, effort or "-", ctx if ctx >= 0 else "-"))

    # Trace de diagnostic : noms des champs reçus et contenu de context_window (uniquement des nombres).
    cw = data.get("context_window")
    sid = str(data.get("session_id") or "")[:8]
    raw_info = " | session=" + sid + " | champs=%s | context_window=%s | effort=%s | rate_limits=%s" % (
        ",".join(sorted(data.keys())),
        json.dumps(cw, separators=(",", ":")) if isinstance(cw, dict) else cw,
        data.get("effort"),
        "oui" if limits else "non",
    )
    push({"cc": {"m": model, "e": effort, "c": ctx, "h": h5, "d": d7}}, raw_info)


if __name__ == "__main__":
    main()

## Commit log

2026-10-04 Port de claude-desktop-buddy vers ESP32-S3 + écran rond GC9A01
    - Couche de compatibilité M5StickCPlus (écran TFT_eSPI, rétroéclairage PWM,
    boutons tactiles TTP223, horloge logicielle) pour garder le firmware d'origine
    - Espèce "clawd" (mascotte Claude Code) en pixel-art avec 7 états animés
    - Tableau de bord de veille (heure, tokens, niveau, sessions, Bluetooth)
    - Modes 1 bouton (gestes) et 2 boutons
    - Upload via esptool récent (reset automatique sur l'USB natif de l'S3)
    - Documentation: WIRING.md, BATTERY.md (schéma, non implémenté)
2026-10-04 add 3dPArts and img
    [Corps principal.stl, Trappe.stl, claud_toy.f3d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]
2026-10-04 Documentation: illustrations, BOM, schéma de câblage, boîtier 3D
    - README: images du boîtier, planche des états de Clawd, BOM, tableau de câblage, section boîtier 3D
    - docs/wiring.svg: schéma de câblage ESP32-S3 / GC9A01 / modules tactiles
    - images/clawd_states.png: rendu illustratif des 7 états
    - WIRING.md: schéma intégré, BLK facultatif
2026-10-04 README: informations affichées, états de Clawd, lien vers la doc officielle d'appairage
2026-10-04 Clawd occupé dès une session, texte des demandes remonté, formatage auto de LittleFS
    - derive(): état busy dès 1 session en cours (3 dans le projet d'origine)
    - drawApproval/drawHUD: bloc de texte relevé au-dessus du bord bas du cercle
    - character: formate LittleFS au premier démarrage si le montage échoue
    - journal de débogage: ajout des compteurs de sessions (désactivé par défaut)
2026-10-05 Bague de contexte et infos Claude Code (modèle, effort, quotas) via la status line en USB
    - data.h: message {"cc":{...}} reçu sur le port série, gardé à part du lien Bluetooth
    - main.cpp: bague de 60 points autour de l'écran (contexte), ligne modèle/effort sur la veille,
    bloc Claude Code dans la page Info, texte de veille décalé
    - tools/claudetoy_statusline.py: status line Claude Code qui envoie modèle/effort/%/quotas à la carte
    - README: section dédiée et mise à jour des écrans
2026-10-05 Bague plus petite, valeurs conservées 30 min, trace de diagnostic de la status line
    - main.cpp: rayon de la bague 115 -> 104 px
    - data.h: les infos Claude Code restent valables 30 minutes (au lieu de 2)
    - tools/claudetoy_statusline.py: trace du dernier passage dans %TEMP%\claudetoy_statusline.last
2026-10-05 Bague de contexte: rayon 98 px
2026-10-05 Status line: noms de modèle et d'effort raccourcis, journal des passages, notes sur la CLI
    - claudetoy_statusline.py: retire les parenthèses du nom du modèle, abrège medium en med,
    journal glissant des 100 derniers passages dans %TEMP%
    - README: testé avec la CLI (appel toutes les 5 s), pas obtenu depuis l'onglet Code de Desktop
2026-10-05 Mod claudetoy-statusline: alimente la bague depuis les mods Claude Code (sans affichage)
    Lit modèle, contexte, quotas ($.session.*) et l'effort (turn.step), puis passe le JSON
    à tools/claudetoy_statusline.py via $.process.run (sans shell, donc Windows possible).
    Claude-Session: https://claude.ai/code/session_017xMLqSQitoRNL2XymEySBW
2026-10-05 hooks.json: ajoute hooks vide pour les chargeurs qui n'acceptent que ce format
    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
2026-10-05 Mod: version 0.1.1 pour déclencher la mise à jour
    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
